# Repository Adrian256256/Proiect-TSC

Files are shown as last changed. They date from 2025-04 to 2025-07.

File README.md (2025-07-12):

# E-Book Reader
## Project name: OpenBook  
**Author:** Teodor-Adrian Harea (333CA)  

schema_bloc
---

## 1. Core Components  

### 1.1 Microcontroller: ESP32-C6  
| Specification | Details |
|---|---|
| Architecture | 32-bit RISC-V (Wi-Fi 6 802.11ax + Bluetooth 5) |
| Clock Speed | Up to 160 MHz |
| Memory | 320 KB SRAM + 512 KB internal flash (expandable via external NOR flash)|
| Interfaces | 30+ GPIO (SPI×2, I2C×1, UART×2, USB 2.0) |

---

## 2. Peripheral Modules  

### 2.1 E-Paper Display (Waveshare)  
- **Interface:** 4-wire SPI (MOSI/SCK/MISO/CS)  
- **Control Pins:**  
  - `EPD_RST` (Hardware reset)  
  - `EPD_DC` (Data/command selector)  
  - `EPD_BUSY` (Status monitoring)  
- **Power Characteristics:**  
  - 150 mA (active refresh)  
  - 0 mA (static display)  

### 2.2 Environmental Sensor (BME688)  
- **Measurements:** Temp/Humidity/Pressure/VOC  
- **Interface:** I2C (100-400 kHz)  
- **Accuracy:** ±0.5°C, ±3% RH  
- **Power:** 3.6 mA (active), 2.1 µA (sleep)  

### 2.3 Precision RTC (DS3231SN)  
- **Accuracy:** ±2ppm (±1 min/year)  
- **Features:**  
  - Battery backup (VBAT pin)  
  - Alarm interrupts (INT_RTC)  

### 2.4 Storage Solutions  
| Component | Capacity | Interface | Speed |
|---|---|---|---|
| NOR Flash | 64 MB | QSPI | 133 MHz |
| microSD Slot | Expandable | SPI | 25 MHz |

---

## 3. Power Management  

### 3.1 Power Architecture  
- **LiPo Charger:** MCP73831 (5V USB → 4.2V battery)  
- **Voltage Regulation:**  
  - XC6220A331MR-G (3.3V LDO)  
- **Battery Monitoring:** MAX17048G (I2C fuel gauge)  

### 3.2 Power States  
| Mode | Current Draw | Runtime* |
|---|---|---|
| Active (measure + display) | 230 mA | 4h |
| Deep Sleep (RTC only) | 6 µA | 1+ month |

*Assuming 1000mAh battery

---

## 4. Detailed Pin Configuration  

### 4.1 E-Paper Display Control  
| Pin Name | Type | Functionality | ESP32-C6 Connection |
|---|---|---|---|
| `EPD_RST` | Output  | Hardware reset (active low) | GPIO18 |
| `EPD_DC` | Output  | Data/Command selection (SPI mode) | GPIO21 |
| `EPD_BUSY` | Input | Busy status (high during refresh) | GPIO19 |
| `EPD_CS` | Output  | SPI chip select (active low) | GPIO5 |
| `MOSI/SCK` | SPI | Main display data/clock lines | SPI1_HOST |

### 4.2 Storage Interfaces  
#### NOR Flash (W25Q512JVEIQ)  
| Pin | Function | ESP32 Pin |
|---|---|---|
| `FLASH_CS`  | QSPI chip select | GPIO17 |
| `IO0-IO3` | Quad SPI data lines | QSPI bus  |

#### microSD Card Slot  
| Pin | Function | ESP32 Pin |
|---|---|---|
| `SS_SD` | SPI slave select | GPIO4 |
| `CD` | Card detect (optional)  | GPIO22 |

### 4.3 System Management  
| Component | Critical Pins | Purpose |
|---|---|---|
| **RTC** | `SCL`/`SDA` (I2C) | Timekeeping (DS3231SN) |
| | `INT_RTC` | Wake-up alarm interrupt |
| **Power** | `VBAT` | RTC backup battery (3V) |
| | `CHG_STAT` | LiPo charger status LED |

### 4.4 User Interface  
| Pin | Type | Functionality |
|---|---|---|
| `PAGE_UP` | GPIO | Tactile button (internal pullup)|
| `PAGE_DN` | GPIO | With debounce circuit |
| `PWR_HLD` | Output | Maintains power when pressed |

### 4.5 Debug Interfaces  
| Interface | Pins Used | Baud Rate |
|---|---|---|
| USB-C | `DP`/`DM` | 12 Mbps |
| UART0 | `TX0`/`RX0` | 115200 |

---

## 5. Optimization Strategies  

### 5.1 Low-Power Techniques  
- Dynamic clock scaling (160 MHz → 10 MHz when idle)  
- Peripheral power gating (MOSFET control for EPD/sensors)  
- SPI/I2C bus deactivation between transactions  

### 5.2 Data Logging Workflow  
1. Wake from deep sleep (RTC/alarm)  
2. Power sensors via GPIO  
3. Acquire measurements (BME688)  
4. Store to flash/SD  
5. Update EPD if threshold exceeded  
6. Return to deep sleep

### **Bill of Materials (BOM)**

| Category | Component | Description | Mouser Link | Datasheet Link |
|---|---|---|---|---|
| **Microcontrollers & Modules** | ESP32-C6-WROOM-1-N8 | WiFi/Bluetooth Module | [Link](https://ro.mouser.com/ProductDetail/Espressif-Systems/ESP32-C6-WROOM-1-N8?qs=8Wlm6%252BaMh8ST02Gmwp74cw%3D%3D) | [Datasheet](https://ro.mouser.com/datasheet/2/891/Espressif_ESP32_C6_WROOM_1__Datasheet_V0_1_PRELIMI-3239987.pdf) |
| | W25Q512JVEIQ | 64MB External NOR Flash | [Link](https://ro.mouser.com/ProductDetail/Winbond/W25Q512JVEIQ?qs=l7cgNqFNU1jw6svr3at6tA%3D%3D) | [Datasheet](https://ro.mouser.com/datasheet/2/949/Winbond_W25Q512JV_Datasheet-3240039.pdf) |
| **Sensors** | BME688 | Environmental Sensor | [Link](https://ro.mouser.com/ProductDetail/Bosch-Sensortec/Evaluation-Kit-Board-BME688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) | [Datasheet](https://ro.mouser.com/datasheet/2/783/Bosch_sensortec_bme688_development_kit_flyer-3000177.pdf) |
| | DS3231SN# | RTC Module | [Link](https://ro.mouser.com/ProductDetail/Analog-Devices-Maxim-Integrated/DS3231SN?qs=1eQvB6Dk1vhUlr8%2FOrV0Fw%3D%3D) | [Datasheet](https://ro.mouser.com/datasheet/2/609/DS3231-3421123.pdf) |
| **Power Management** | MAX17048G+T10 | Battery Fuel Gauge | [Link](https://eu.mouser.com/ProductDetail/Analog-Devices-Maxim-Integrated/MAX17048G+T10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) | [Datasheet](https://eu.mouser.com/datasheet/2/609/MAX17048_MAX17049-3469099.pdf) |
| | MCP73831 | Li-Po Battery Charger | [Link](https://ro.mouser.com/ProductDetail/Microchip-Technology/MCP73831-2DCI-MC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) | [Datasheet](https://ro.mouser.com/datasheet/2/268/MCP73831_Family_Data_Sheet_DS20001984H-3441711.pdf) |
| | XC6220A331MR-G | LDO Voltage Regulator 3.3V | [Link](https://ro.mouser.com/ProductDetail/Torex-Semiconductor/XC6220A331MR-G?qs=AsjdqWjXhJ8ZSWznL1J0gg%3D%3D) | [Datasheet](https://ro.mouser.com/datasheet/2/760/xc6220-3371556.pdf) |
| **Connectors & Protection** | USBLC6-2SC6Y | USB ESD Protection | [Link](https://eu.mouser.com/ProductDetail/STMicroelectronics/USBLC6-2SC6Y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) | [Datasheet](https://ro.mouser.com/datasheet/2/389/usblc6_2sc6y-1852505.pdf) |
| | FH34SRJ-24S-0.5SH | 24-pin Connector | [Link](https://ro.mouser.com/ProductDetail/Hirose-Connector/FH34SRJ-24S-0.5SH50?qs=iyLo5FA4poC8fzWlavnA7A%3D%3D) | [Datasheet](https://ro.mouser.com/datasheet/2/185/FH34SRJ_24S_0_5SH_50__CL0580_1255_6_50_2DDrawing_0-1615030.pdf) |
| **Passive Components** | SD0805S020S1R0 | 68μH Inductor | [Link](https://ro.mouser.com/ProductDetail/KYOCERA-AVX/SD0805S020S1R0?qs=jCA%252BPfw4LHbpkAoSnwrdjw%3D%3D) | [Datasheet](https://ro.mouser.com/datasheet/2/40/schottky-3165252.pdf) |
| | MBR0530 | Schottky Diode | [Link](https://ro.mouser.com/ProductDetail/onsemi-Fairchild/MBR0530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) | [Datasheet](https://ro.mouser.com/datasheet/2/308/MBR0530_D-1810985.pdf) |

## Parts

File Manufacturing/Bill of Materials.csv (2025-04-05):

Qty | Value | Device | Package | Parts | Description | ARROW_PART_NUMBER | ARROW_PRICE-STOCK | AVAILABILITY | CENTROID_NOT_SPECIFIED | CHECK_PRICES | COPYRIGHT | DATASHEET | DESCRIPTION | DIGIKEY_DESCRIPTION | DIGIKEY_PART_NUMBER | HEIGHT | LEAD_FREE | MANUFACTURER_NAME | MANUFACTURER_PART_NUMBER | MF | MFR_NAME | MOUSER_PART_NUMBER | MOUSER_PRICE-STOCK | MOUSER_TESTING_PART_NUMBER | MOUSER_TESTING_PRICE-STOCK | MP | MPN | PACKAGE | POPULARITY | PREFIX | PRICE | PROD_ID | PURCHASE-URL | ROHS | SNAPEDA_LINK | SPICEMODEL | SPICEPREFIX | TEMPERATURE_RANGE_HIGH | TEMPERATURE_RANGE_LOW | TP_SIGNAL_NAME | VALUE
1 | 0.1uF/50V | EAGLE-LTSPICE_CC0402 | EAGLE-LTSPICE_C0402 | EPD_C5 | CAPACITOR, European symbol |  |  |  |  |  |  |  |  |  |  |  |  |  |  |  |  |  |  |  |  |  |  |  |  |  |  |  |  |  |  | NONE | C
1 | 0.47 | ESP32_WROVER_EAGLE-LTSPICE_RR0402 | ESP32_WROVER_EAGLE-LTSPICE_R0402 | R3 | RESISTOR, European symbol |  |  |  |  |  |  |  |  |  |  |  |  |  |  |  |  |  |  |  |  |  |  |  |  |  |  |  |  |  |  | NONE | R
1 | 1 | ADAFRUIT_LEDCHIP-LED0603 | ADAFRUIT_CHIP-LED0603 | CHG_LED | LED
1 | 1 | SJ | SJ | SJ1 | SMD solder JUMPER |  |  |  |  |  |  |  |  |  |  |  |  |  |  |  |  |  |  |  |  |  |  |  | 3
1 | 100K | ESP32_WROVER_EAGLE-LTSPICE_RR0402 | ESP32_WROVER_EAGLE-LTSPICE_R0402 | R1_PWRUSB | RESISTOR, European symbol |  |  |  |  |  |  |  |  |  |  |  |  |  |  |  |  |  |  |  |  |  |  |  |  |  |  |  |  |  |  | NONE | R
8 | 100nF | EAGLE-LTSPICE_CC0402 | EAGLE-LTSPICE_C0402 | C1, C2, C4_USB, C6, C8, C9, C10, C_DELAY | CAPACITOR, European symbol |  |  |  |  |  |  |  |  |  |  |  |  |  |  |  |  |  |  |  |  |  |  |  |  |  |  |  |  |  |  | NONE | C
1 | 100uF TANT | RCL_CPOL-EUCT3528 | RCL_CT3528 | C3 | POLARIZED CAPACITOR, European symbol |  |  |  |  |  |  |  |  |  |  |  |  |  |  |  |  |  |  |  |  |  |  |  | 0 |  |  |  |  |  |  |  | C
16 | 10K | ESP32_WROVER_EAGLE-LTSPICE_RR0402 | ESP32_WROVER_EAGLE-LTSPICE_R0402 | R1, R1_PINH, R1_PINH1, R2-PINH, R2-PINH1, R4, R5, R6, R7, R8, R9, R10, R_BOOT, R_CHANGE, R_CL1, R_RESET | RESISTOR, European symbol |  |  |  |  |  |  |  |  |  |  |  |  |  |  |  |  |  |  |  |  |  |  |  |  |  |  |  |  |  |  | NONE | R
1 | 10uF | EAGLE-LTSPICE_CC0402 | EAGLE-LTSPICE_C0402 | C7 | CAPACITOR, European symbol |  |  |  |  |  |  |  |  |  |  |  |  |  |  |  |  |  |  |  |  |  |  |  |  |  |  |  |  |  |  | NONE | C
1 | 112A-TAAR-R03_ATTEND | 112A-TAAR-R03_ATTEND | 112ATAARR03ATTEND | J4 | Micro SD Card Socket, Push-Push Type, Top Mount, SMT, H=1.83mm, 10u |  |  |  |  |  |  |  | Micro SD Card Socket | Push-Push Type | Top Mount | SMT | H=1.83mm | 10u |  |  | 1.9mm |  | ATTEND | 112A-TAAR-R03 ATTEND
1 | 15 | ESP32_WROVER_EAGLE-LTSPICE_RR0402 | ESP32_WROVER_EAGLE-LTSPICE_R0402 | R_CAPACITOR | RESISTOR, European symbol |  |  |  |  |  |  |  |  |  |  |  |  |  |  |  |  |  |  |  |  |  |  |  |  |  |  |  |  |  |  | NONE | R
1 | 1uF | EAGLE-LTSPICE_CC0402 | EAGLE-LTSPICE_C0402 | C5 | CAPACITOR, European symbol |  |  |  |  |  |  |  |  |  |  |  |  |  |  |  |  |  |  |  |  |  |  |  |  |  |  |  |  |  |  | NONE | C
9 | 1uF/50V | EAGLE-LTSPICE_CC0402 | EAGLE-LTSPICE_C0402 | EPD_C1, EPD_C2, EPD_C6, EPD_C7, EPD_C8, EPD_C9, EPD_C10, EPD_C11, EPD_C12 | CAPACITOR, European symbol |  |  |  |  |  |  |  |  |  |  |  |  |  |  |  |  |  |  |  |  |  |  |  |  |  |  |  |  |  |  | NONE | C
1 | 2.2 | ESP32_WROVER_EAGLE-LTSPICE_RR0402 | ESP32_WROVER_EAGLE-LTSPICE_R0402 | R2 | RESISTOR, European symbol |  |  |  |  |  |  |  |  |  |  |  |  |  |  |  |  |  |  |  |  |  |  |  |  |  |  |  |  |  |  | NONE | R
1 | 200 | ESP32_WROVER_EAGLE-LTSPICE_RR0402 | ESP32_WROVER_EAGLE-LTSPICE_R0402 | R1_BAT | RESISTOR, European symbol |  |  |  |  |  |  |  |  |  |  |  |  |  |  |  |  |  |  |  |  |  |  |  |  |  |  |  |  |  |  | NONE | R
2 | 20V/4.2A/52mO/1.4W | ESP32_WROVER_SPARKFUN-DISCRETESEMI_MOSFET_PCH-DMG2305UX-7 | ESP32_WROVER_SPARKFUN-DISCRETESEMI_SOT23-3 | Q1, Q2 | P-channel MOSFETs |  |  |  |  |  |  |  |  |  |  |  |  |  |  |  |  |  |  |  |  |  |  |  |  |  |  | TRAN-14388 |  |  |  |  |  |  |  |  | 20V/4.2A/52mO/1.4W
1 | 2K | ESP32_WROVER_EAGLE-LTSPICE_RR0402 | ESP32_WROVER_EAGLE-LTSPICE_R0402 | R2_BAT | RESISTOR, European symbol |  |  |  |  |  |  |  |  |  |  |  |  |  |  |  |  |  |  |  |  |  |  |  |  |  |  |  |  |  |  | NONE | R
5 | 4.7uF | EAGLE-LTSPICE_CC0402 | EAGLE-LTSPICE_C0402 | C1_BAT, C1_BAT1, C1_BAT2, C2_BAT, C5_USB | CAPACITOR, European symbol |  |  |  |  |  |  |  |  |  |  |  |  |  |  |  |  |  |  |  |  |  |  |  |  |  |  |  |  |  |  | NONE | C
1 | 4.7uF/25V | EAGLE-LTSPICE_CC0402 | EAGLE-LTSPICE_C0402 | C4 | CAPACITOR, European symbol |  |  |  |  |  |  |  |  |  |  |  |  |  |  |  |  |  |  |  |  |  |  |  |  |  |  |  |  |  |  | NONE | C
2 | 5k1 | ESP32_WROVER_EAGLE-LTSPICE_RR0402 | ESP32_WROVER_EAGLE-LTSPICE_R0402 | R2-USB, R2-USB1 | RESISTOR, European symbol |  |  |  |  |  |  |  |  |  |  |  |  |  |  |  |  |  |  |  |  |  |  |  |  |  |  |  |  |  |  | NONE | R
1 | 68uH | 744043680IND_4828-WE-TPC_WRE | IND_4828-WE-TPC_WRE | L1 |  |  |  |  |  |  | Copyright (C) 2024 Ultra Librarian. All rights reserved. |  |  |  |  |  |  |  | 744043680 |  | Wurth Electronics
1 | BD5229G-TR | BD5229G-TR | SOT95P280X125-5N | IC1 | Voltage Detector with Adjustable Delay Time: CMOS processes are utilized to develop high precision, low current consumption CMOS reset ICs that allow arbitrary setting of the delay time. The extensive lineup includes both Nch Open Drain and CMOS output types in a wide range of detection voltages (from 2.3V to 6.0V, in 0.1V steps), enabling selection of the ideal solution based on customer requirements. In addition, the entire series is of course both lead-free and RoHS-compliant. |  |  |  |  |  |  |  | Voltage Detector with Adjustable Delay Time: CMOS processes are utilized to develop high precision | low current consumption CMOS reset ICs that allow arbitrary setting of the delay time. The extensive lineup includes both Nch Open Drain and CMOS output types in a wide range of detection voltages (from 2.3V to 6.0V | in 0.1V steps) | enabling selection of the ideal solution based on customer requirements. In addition | the entire series is of course both lead-free and RoHS-compliant. |  |  | 1.25mm |  | ROHM Semiconductor | BD5229G-TR |  |  | 755-BD5229G-TR | https://www.mouser.co.uk/ProductDetail/ROHM-Semiconductor/BD5229G-TR?qs=4kLU8WoGk0vvnhrrYwdszw%3D%3D
3 | BUTTON_CUSYOMV1 | BUTTON_CUSYOMV1 | MYBUTTON | BOOT_BUTTON, CHANGE_BUTTON, RESET_BUTTON
1 | CPH3225A | CPH3225A | CAPCP3225X100N | C10_SUPERCAP | Cap 0.011F 3.3V 1210 Flat Check availability |  |  | Not in stock |  | https://www.snapeda.com/parts/CPH3225A/Seiko+Instruments/view-part/?ref=eda |  |  | 11 mF (EDLC) Supercapacitor 3.3 V 1210 (3225 Metric) - - |  |  |  |  |  |  | Seiko Instruments |  |  |  |  |  | CPH3225A |  | 1210 Seiko |  |  | None |  | https://www.snapeda.com/api/url_track_click_mouser/?unipart_id=562593&manufacturer=Seiko Instruments&part_name=CPH3225A&search_term=None |  | https://www.snapeda.com/parts/CPH3225A/Seiko+Instruments/view-part/?ref=snap
1 | DS3231SN# | DS3231SN# | SOIC127P1032X265-16N | U3 | Real Time Clock Serial 16-Pin SOIC W T/R Check availability |  |  | In Stock |  | https://www.snapeda.com/parts/DS3231SN%23/Analog+Devices/view-part/?ref=eda |  |  | Extremely Accurate I²C-Integrated RTC/TCXO/Crystal |  |  |  |  |  |  | Analog Devices |  |  |  |  |  | DS3231SN# |  | SOIC-16 Maxim |  |  | None |  | https://www.snapeda.com/api/url_track_click_mouser/?unipart_id=99048&manufacturer=Analog Devices&part_name=DS3231SN#&search_term=None |  | https://www.snapeda.com/parts/DS3231SN%23/Analog+Devices/view-part/?ref=snap
1 | ESP32-C6-WROOM-1-N8 | ESP32-C6-WROOM-1-N8 | XCVR_ESP32-C6-WROOM-1-N8 | U2 | Check availability |  |  | In Stock |  | https://www.snapeda.com/parts/ESP32-C6-WROOM-1-N8/Espressif+Systems/view-part/?ref=eda |  |  | Multiprotocol Modules ESP32-C6 module | Wi-Fi 6 in 2.4 GHz band | Bluetooth 5 | Zigbee 3.0 and Thread. ESP34-WROOM Compatible - ENGINEERING SAMPLE |  |  |  |  |  |  | Espressif Systems |  |  |  |  |  | ESP32-C6-WROOM-1-N8 |  | None |  |  | None |  |  |  | https://www.snapeda.com/parts/ESP32-C6-WROOM-1-N8/Espressif+Systems/view-part/?ref=snap
1 | ESP32C6_VARISTORCN1812 | ESP32C6_VARISTORCN1812 | ESP32C6_VARISTOR_CT/CN1812 | PFMF.050.1 | VARISTOR |  |  |  |  |  |  |  |  |  |  |  |  |  |  |  |  |  |  |  |  |  |  |  | 0
2 | ESP32_WROVER_AVX---SD0805S020S1R0_AVX_SD0805S020S1R0_0_0AVX_SD0805S020S1R0_0_0 | ESP32_WROVER_AVX---SD0805S020S1R0_AVX_SD0805S020S1R0_0_0AVX_SD0805S020S1R0_0_0 | ESP32_WROVER_AVX---SD0805S020S1R0_AVX_SD0805S020S1R0_0 | D2, D7 | Schottky Barrier Rectifier Diode |  |  |  | No |  |  | http://datasheets.avx.com/schottky.pdf |  | DIODE SCHOTTKY 20V 1A 0805 | 478-7800-1-ND |  | yes |  |  | AVX |  | 581-SD0805S020S1R0 |  |  |  |  |  | 0805 (2012 metric) |  | D |  |  |  | yes |  |  |  | +125°C | -55°C
1 | ESP32_WROVER_BME680_BME680 | ESP32_WROVER_BME680_BME680 | ESP32_WROVER_BME680_PSON80P300X300X100-8N | SENSOR2 | Integrated Environmental Unit |  |  | Unavailable |  |  |  |  | Integrated Environmental Unit |  |  |  |  |  |  | Bosch Sensortec |  |  |  |  |  | BME680 |  | LGA-8 Bosch Tools |  |  | None
1 | ESP32_WROVER_SPARKFUN-IC-POWER_MCP73831 | ESP32_WROVER_SPARKFUN-IC-POWER_MCP73831 | ESP32_WROVER_SPARKFUN-IC-POWER_SOT23-5 | MCP73831 | MCP73831T Li-Ion, Li-Pol Controller |  |  |  |  |  |  |  |  |  |  |  |  |  |  |  |  |  |  |  |  |  |  |  |  |  |  | IC-09995
1 | FH34SRJ-24S-0.5SH_99_ | FH34SRJ-24S-0.5SH_99_ | FH34SRJ24S05SH99 | J1 | (0.50mm) Surface Mount, Right Angle |  |  |  |  |  |  |  | 24 Position FFC | FPC Connector Contacts | (0.50mm) Surface Mount | Right Angle |  |  | 1.1mm |  | Hirose | FH34SRJ-24S-0.5SH(99) |  |  | 798-FH34SRJ24S05SH99 | https://www.mouser.co.uk/ProductDetail/Hirose-Connector/FH34SRJ-24S-0.5SH99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
1 | MAX17048G+T10 | MAX17048G+T10 | SON50P200X200X80-9N | U4 | Check availability |  |  | In Stock |  | https://www.snapeda.com/parts/MAX17048G+T10/Analog+Devices/view-part/?ref=eda |  |  | 3µA 1-Cell/2-Cell Fuel Gauge with ModelGauge |  |  |  |  |  |  | Analog Devices |  |  |  |  |  | MAX17048G+T10 |  | TDFN-8 Maxim |  |  | None |  | https://www.snapeda.com/api/url_track_click_mouser/?unipart_id=329239&manufacturer=Analog Devices&part_name=MAX17048G+T10&search_term=None |  | https://www.snapeda.com/parts/MAX17048G+T10/Analog+Devices/view-part/?ref=snap
3 | MBR0530 | MBR0530 | SOD3716X135N | D3, D4, D5 | ON SEMICONDUCTOR - MBR0530 - DIODE, SCHOTTKY, 0.5A, 30V, SOD-123 |  |  | In Stock |  | https://www.snapeda.com/parts/MBR0530/Onsemi/view-part/?ref=eda |  |  | Diode Schottky 30 V 500mA Surface Mount SOD-123 |  |  |  |  |  |  | ON Semiconductor |  |  |  |  |  | MBR0530 |  | SOD-123-2 ON Semiconductor |  |  | None |  | https://www.snapeda.com/api/url_track_click_mouser/?unipart_id=179458&manufacturer=ON Semiconductor&part_name=MBR0530&search_term=None |  | https://www.snapeda.com/parts/MBR0530/Onsemi/view-part/?ref=snap
6 | PGB1010603MR | PGB1010603MR | DIOC1608X36N | D6, D8, D9, D10, D11, D12 | Check availability |  |  | In Stock |  | https://www.snapeda.com/parts/PGB1010603MR/Littelfuse/view-part/?ref=eda |  |  | 150V (Typ) Clamp - Ipp Tvs Diode Surface Mount 0603 (1608 Metric) |  |  |  |  |  |  | Littelfuse Inc. |  |  |  |  |  | PGB1010603MR |  | 0603 Littelfuse Inc. |  |  | None |  | https://www.snapeda.com/api/url_track_click_mouser/?unipart_id=5659453&manufacturer=Littelfuse Inc.&part_name=PGB1010603MR&search_term=None |  | https://www.snapeda.com/parts/PGB1010603MR/Littelfuse/view-part/?ref=snap
1 | QWIIC_RIGHT_ANGLE | QWIIC_CONNECTORJS-1MM | JST04_1MM_RA | J3 | SparkFun I2C Standard Qwiic Connector |  |  |  |  |  |  |  |  |  |  |  |  |  |  |  |  |  |  |  |  |  |  |  |  |  |  | CONN-13694 |  |  |  |  |  |  |  |  | QWIIC_RIGHT_ANGLE
1 | SAMACSYS_PARTS_USB4110-GF-A | SAMACSYS_PARTS_USB4110-GF-A | SAMACSYS_PARTS_USB4110GFA | J2 | CONN USB 2.0 TYPE-C R/A SMT |  |  |  |  |  |  |  | CONN USB 2.0 TYPE-C R/A SMT |  |  | 3.26mm |  | GCT (GLOBAL CONNECTOR TECHNOLOGY) | USB4110-GF-A |  |  | 640-USB4110-GF-A | https://www.mouser.co.uk/ProductDetail/GCT/USB4110-GF-A?qs=KUoIvG%2F9IlYiZvIXQjyJeA%3D%3D
1 | SI1308EDL-T1-GE3 | SI1308EDL-T1-GE3 | SOT65P210X110-3N | Q3 | MOSFET N-Ch 30V 1.5A TrenchFET SC70 Vishay Si1308EDL-T1-GE3 N-channel MOSFET Transistor, 1.5 A, 30 V, 3-Pin SC-70 |  |  | In Stock |  | https://www.snapeda.com/parts/SI1308EDL-T1-GE3/Vishay+Siliconix/view-part/?ref=eda |  |  | Si1308EDL-T1-GE3 N-channel MOSFET Transistor | 1.5 A | 30 V | 3-Pin SC-70 | Siliconix / Vishay SI1308EDL-T1-GE3 |  |  |  |  |  |  | Vishay Siliconix |  |  |  |  |  | SI1308EDL-T1-GE3 |  | SOT-323 Vishay Semiconductor |  |  | None |  | https://www.snapeda.com/api/url_track_click_mouser/?unipart_id=274603&manufacturer=Vishay Siliconix&part_name=SI1308EDL-T1-GE3&search_term=None |  | https://www.snapeda.com/parts/SI1308EDL-T1-GE3/Vishay+Siliconix/view-part/?ref=snap
17 | TPTP20R | TPTP20R | TP20R | TP1, TP2, TP3, TP4, TP5, TP6, TP7, TP8, TP9, TP10, TP11, TP12, TP13, TP14, TP15, TP16, TP17 | Test pad |  |  |  |  |  |  |  |  |  |  |  |  |  |  |  |  |  |  |  |  |  |  |  | 2
1 | USBLC6-2SC6Y | USBLC6-2SC6Y | SOT95P280X145-6N | D1 | Low Cap. ESD Protection Auto SOT-23-6 STMicroelectronics USBLC6-2SC6Y, Dual Uni-Directional TVS Diode Array, 6-Pin SOT-23 |  |  | In Stock |  | https://www.snapeda.com/parts/USBLC6-2SC6Y/STMicroelectronics/view-part/?ref=eda |  |  | 17V Clamp 5A (8/20µs) Ipp Tvs Diode Surface Mount SOT-23-6 |  |  |  |  |  |  | STMicroelectronics |  |  |  |  |  | USBLC6-2SC6Y |  | SOT-23-6 STMicroelectronics |  |  | None |  |  |  | https://www.snapeda.com/parts/USBLC6-2SC6Y/STMicroelectronics/view-part/?ref=snap
1 | W25Q512JVEIQ | W25Q512JVEIQ | SON127P600X800X80-9N | U1 | Check availability |  |  | In Stock |  | https://www.snapeda.com/parts/W25Q512JVEIQ/Winbond+Electronics/view-part/?ref=eda |  |  | FLASH - NOR Memory IC 512Mb (64M x 8) SPI - Quad I/O 133 MHz 8-WSON (8x6) |  |  |  |  |  |  | Winbond Electronics |  |  |  |  |  | W25Q512JVEIQ |  | Package |  |  | None |  |  |  | https://www.snapeda.com/parts/W25Q512JVEIQ/Winbond+Electronics/view-part/?ref=snap
1 | XC6220A331MR-G | XC6220A331MR-G | SOT95P280X120-5N | IC4 | LDO Voltage Regulators |  |  |  |  |  |  |  | LDO Voltage Regulators |  |  | 1.2mm |  | Torex | XC6220A331MR-G |  |  | 865-XC6220A331MR-G | https://www.mouser.co.uk/ProductDetail/Torex-Semiconductor/XC6220A331MR-G?qs=AsjdqWjXhJ8ZSWznL1J0gg%3D%3D

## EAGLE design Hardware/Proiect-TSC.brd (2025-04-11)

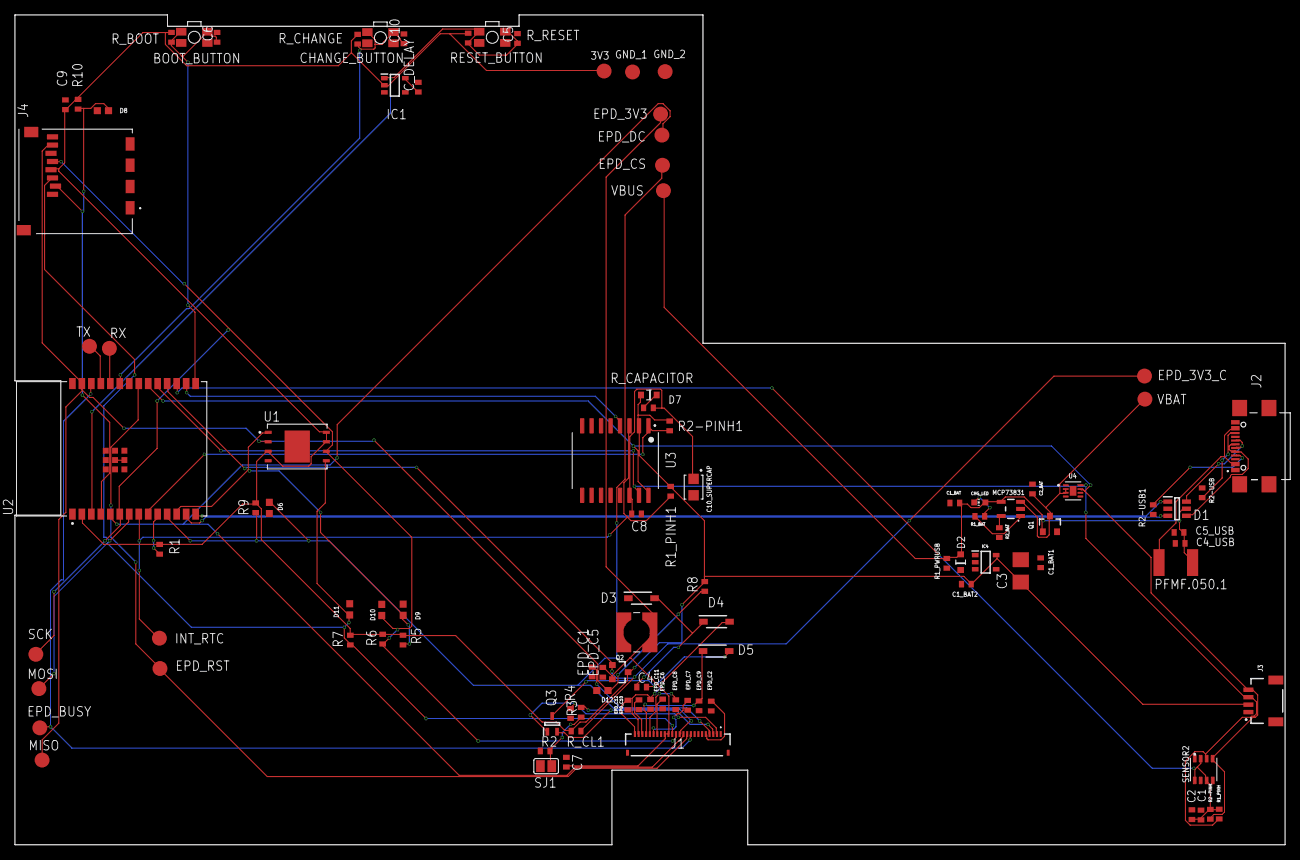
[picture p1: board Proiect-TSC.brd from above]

Board: 2 copper layers, 170.2 x 111.2 mm, 103 parts (0 on the bottom side), 54 nets.

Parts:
3V3: TPTP20R; TP20R
BOOT_BUTTON: BUTTON_CUSYOMV1; MYBUTTON
C1, C2, C4_USB, C6, C8, C9, C10: 100nF; EAGLE-LTSPICE_C0402
C1_BAT, C1_BAT1, C1_BAT2, C2_BAT, C5_USB: 4.7uF; EAGLE-LTSPICE_C0402
C3: 100uF TANT; RCL_CT3528
C4: 4.7uF/25V; EAGLE-LTSPICE_C0402
C5: 1uF; EAGLE-LTSPICE_C0402
C7: 10uF; EAGLE-LTSPICE_C0402
C10_SUPERCAP: CPH3225A; CAPCP3225X100N
CHANGE_BUTTON: BUTTON_CUSYOMV1; MYBUTTON
CHG_LED: 1; ADAFRUIT_CHIP-LED0603
C_DELAY: 100nF; EAGLE-LTSPICE_C0402
D1: USBLC6-2SC6Y; SOT95P280X145-6N
D2, D7: ESP32_WROVER_AVX---SD0805S020S1R0_AVX_SD0805S020S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; ESP32_WROVER_AVX---SD0805S020S1R0_AVX_SD0805S020S1R0_0
D3, D4, D5: MBR0530; SOD3716X135N
D6, D8, D9, D10, D11, D12: PGB1010603MR; DIOC1608X36N
EPD_3V3, EPD_3V3_C: TPTP20R; TP20R
EPD_BUSY: TPTP20R; TP20R
EPD_C1, EPD_C2, EPD_C6, EPD_C7, EPD_C8, EPD_C9, EPD_C10, EPD_C11, EPD_C12: 1uF/50V; EAGLE-LTSPICE_C0402
EPD_C5: 0.1uF/50V; EAGLE-LTSPICE_C0402
EPD_CS: TPTP20R; TP20R
EPD_DC: TPTP20R; TP20R
EPD_RST: TPTP20R; TP20R
GND_1, GND_2: TPTP20R; TP20R
IC1: BD5229G-TR; SOT95P280X125-5N
IC4: XC6220A331MR-G; SOT95P280X120-5N
INT_RTC: TPTP20R; TP20R
J1: FH34SRJ-24S-0.5SH_99_; FH34SRJ24S05SH99
J2: SAMACSYS_PARTS_USB4110-GF-A; SAMACSYS_PARTS_USB4110GFA
J3: QWIIC_RIGHT_ANGLE; JST04_1MM_RA
J4: 112A-TAAR-R03_ATTEND; 112ATAARR03ATTEND
L1: 68uH; IND_4828-WE-TPC_WRE
MCP73831: ESP32_WROVER_SPARKFUN-IC-POWER_MCP73831; ESP32_WROVER_SPARKFUN-IC-POWER_SOT23-5
MISO: TPTP20R; TP20R
MOSI: TPTP20R; TP20R
PFMF.050.1: ESP32C6_VARISTORCN1812; ESP32C6_VARISTOR_CT/CN1812
Q1, Q2: 20V/4.2A/52mΩ/1.4W; ESP32_WROVER_SPARKFUN-DISCRETESEMI_SOT23-3
Q3: SI1308EDL-T1-GE3; SOT65P210X110-3N
R1, R1_PINH, R1_PINH1, R2-PINH, R2-PINH1, R4, R5, R6, R7, R8, R9, R10: 10K; ESP32_WROVER_EAGLE-LTSPICE_R0402
R1_BAT: 200; ESP32_WROVER_EAGLE-LTSPICE_R0402
R1_PWRUSB: 100K; ESP32_WROVER_EAGLE-LTSPICE_R0402
R2: 2.2; ESP32_WROVER_EAGLE-LTSPICE_R0402
R2-USB, R2-USB1: 5k1; ESP32_WROVER_EAGLE-LTSPICE_R0402
R2_BAT: 2K; ESP32_WROVER_EAGLE-LTSPICE_R0402
R3: 0.47; ESP32_WROVER_EAGLE-LTSPICE_R0402
RESET_BUTTON: BUTTON_CUSYOMV1; MYBUTTON
RX: TPTP20R; TP20R
R_BOOT: 10K; ESP32_WROVER_EAGLE-LTSPICE_R0402
R_CAPACITOR: 15; ESP32_WROVER_EAGLE-LTSPICE_R0402
R_CHANGE: 10K; ESP32_WROVER_EAGLE-LTSPICE_R0402
R_CL1: 10K; ESP32_WROVER_EAGLE-LTSPICE_R0402
R_RESET: 10K; ESP32_WROVER_EAGLE-LTSPICE_R0402
SCK: TPTP20R; TP20R
SENSOR2: ESP32_WROVER_BME680_BME680; ESP32_WROVER_BME680_PSON80P300X300X100-8N
SJ1: 1; SJ
TX: TPTP20R; TP20R
U1: W25Q512JVEIQ; SON127P600X800X80-9N
U2: ESP32-C6-WROOM-1-N8; XCVR_ESP32-C6-WROOM-1-N8
U3: DS3231SN#; SOIC127P1032X265-16N
U4: MAX17048G+T10; SON50P200X200X80-9N
VBAT: TPTP20R; TP20R
VBUS: TPTP20R; TP20R

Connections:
3V3: 3V3.TP, C1_BAT2.1, C3.+, C9.1, D7.2, IC1.2, IC4.5, J3.2, J4.P4, Q2.3, R1.2, R1_PINH1.2, R2-PINH1.2, R5.2, R6.2, R7.2, R8.2, R9.2, R10.2, R_BOOT.2, R_CHANGE.2, R_CL1.2, R_RESET.2, U1.3, U1.7, U1.8, U2.2, U3.2
32KHZ: R2-PINH1.1, U2.9, U3.1
DN: D1.4, J2.A7, J2.B7
DP: D1.6, J2.A6, J2.B6
EPD_3V3: C7.1, EPD_3V3.TP, EPD_C5.2, J1.15, J1.16, L1.2, Q2.2
EPD_3V3_C: EPD_3V3_C.TP, Q2.1, R_CL1.1, U2.18
EPD_BUSY: EPD_BUSY.TP, J1.9, U2.26
EPD_CS: D6.1, EPD_CS.TP, J1.12, R9.1, U2.11
EPD_DC: EPD_DC.TP, J1.11, U2.5
EPD_RST: EPD_RST.TP, J1.10, U2.21
FLASH_CS: D9.1, R5.1, U1.1, U2.12
GDR: J1.2, Q3.1, R4.2
GND: BOOT_BUTTON.2, C1.2, C1_BAT.2, C1_BAT1.1, C1_BAT1.2, C1_BAT2.2, C2.2, C2_BAT.2, C3.-, C4_USB.2, C5.2, C5_USB.2, C6.2, C7.2, C8.2, C9.2, C10.2, C10_SUPERCAP.2, CHANGE_BUTTON.2, C_DELAY.2, D1.2, D2.1, D3.1, D6.2, D8.2, D9.2, D10.2, D11.2, D12.2, EPD_C1.1, EPD_C2.1, EPD_C5.1, EPD_C6.1, EPD_C7.1, EPD_C8.1, EPD_C9.1, EPD_C10.1, EPD_C11.1, EPD_C12.1, GND_1.TP, GND_2.TP, IC1.3, IC4.1, IC4.2, IC4.3, J1.8, J1.17, J1.MP1, J1.MP2, J2.A1, J2.A12, J2.B1, J2.B12, J2.MP1, J2.MP2, J2.MP3, J2.MP4, J3.1, J4.G1, J4.G2, J4.G3, J4.G4, J4.P6, MCP73831.2, Q1.2, R1_PWRUSB.1, R2.1, R2-USB.2, R2-USB1.1, R2_BAT.1, R4.1, RESET_BUTTON.2, SENSOR2.1, SENSOR2.5, SENSOR2.7, SJ1.1, U1.4, U1.9, U2.1, U2.28, U2.29_1, U2.29_2, U2.29_3, U2.29_4, U2.29_5, U2.29_6, U2.29_7, U2.29_8, U2.29_9, U3.13, U4.1, U4.4, U4.6, U4.9
GPIO8: R1.1, U2.10
I2C_PW: C1.1, C2.1, R1_PINH.2, R2-PINH.2, SENSOR2.2, SENSOR2.6, SENSOR2.8, U2.17
INT_RTC: INT_RTC.TP, R1_PINH1.1, U2.8, U3.3
IO/BOOT: BOOT_BUTTON.3, BOOT_BUTTON.4, C6.1, R_BOOT.1, U2.15
IO/CHANGE: C10.1, CHANGE_BUTTON.3, CHANGE_BUTTON.4, R_CHANGE.1, U2.23
MISO: D12.1, J4.P7, MISO.TP, R8.1, U1.2, U2.27
MOSI: D11.1, J1.14, J4.P3, MOSI.TP, R7.1, U1.5, U2.7
unnamed: J2.A5, R2-USB1.2
unnamed: C_DELAY.1, IC1.5
unnamed: CHG_LED.C, R1_BAT.1
unnamed: C4.1, D3.2, D4.1
unnamed: MCP73831.1, R1_BAT.2
unnamed: D7.1, R_CAPACITOR.1
unnamed: MCP73831.5, R2_BAT.2
unnamed: J2.B5, R2-USB.1
unnamed: EPD_C12.2, J1.24
unnamed: EPD_C1.2, J1.4
unnamed: EPD_C2.2, J1.5
unnamed: EPD_C6.2, J1.18
unnamed: EPD_C7.2, J1.19
unnamed: EPD_C8.2, J1.20
unnamed: EPD_C10.2, J1.22
PREVGH: D5.1, EPD_C9.2, J1.21
PREVGL: D4.2, EPD_C11.2, J1.23
RESE: J1.3, Q3.2, R3.2
RESE': R2.2, R3.1, SJ1.2
RESET: C5.1, IC1.1, RESET_BUTTON.3, RESET_BUTTON.4, R_RESET.1, U2.3
RTC_RST: U2.16, U3.4
RX: RX.TP, U2.24
SCK: D10.1, J1.13, J4.P5, R6.1, SCK.TP, U1.6, U2.6
SCL: J3.4, R2-PINH.1, SENSOR2.4, U2.20, U3.16, U4.7
SDA: J3.3, R1_PINH.1, SENSOR2.3, U2.19, U3.15, U4.8
SRC: C4.2, D5.2, L1.1, Q3.3
SS_SD: D8.1, J4.P2, R10.1, U2.4
TX: TX.TP, U2.25
USB_D+: D1.1, U2.14
USB_D-: D1.3, U2.13
VBAT: C2_BAT.1, MCP73831.3, Q1.3, U4.2, U4.3, VBAT.TP
VBUS: C1_BAT.1, C4_USB.1, C5_USB.1, CHG_LED.A, D1.5, D2.2, MCP73831.4, PFMF.050.1.2, Q1.1, R1_PWRUSB.2, VBUS.TP
VRTC: C8.1, C10_SUPERCAP.1, R_CAPACITOR.2, U3.14
VUSB: J2.A4, J2.A9, J2.B4, J2.B9, PFMF.050.1.1

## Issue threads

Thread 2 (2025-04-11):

Etichete test pad-uri în silkscreen

anya718, 2025-04-11:
Test pad-urile trebuie marcate în silkscreen cu numele semnalelor pe care le poartă (MISO, MOSI, Rx, GND, etc.)

Adrian256256, 2025-04-11:
Done!

Closed 2025-04-11.

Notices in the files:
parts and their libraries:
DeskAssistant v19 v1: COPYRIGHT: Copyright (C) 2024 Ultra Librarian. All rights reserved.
